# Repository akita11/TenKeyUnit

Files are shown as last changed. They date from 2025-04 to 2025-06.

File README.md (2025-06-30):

# TenKey UNIT

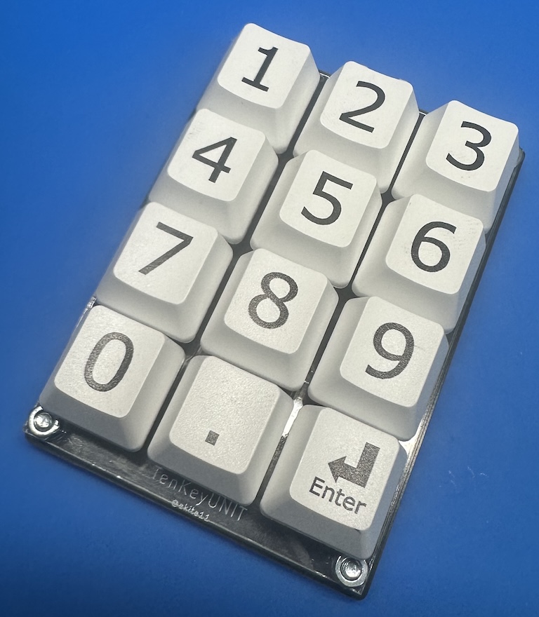
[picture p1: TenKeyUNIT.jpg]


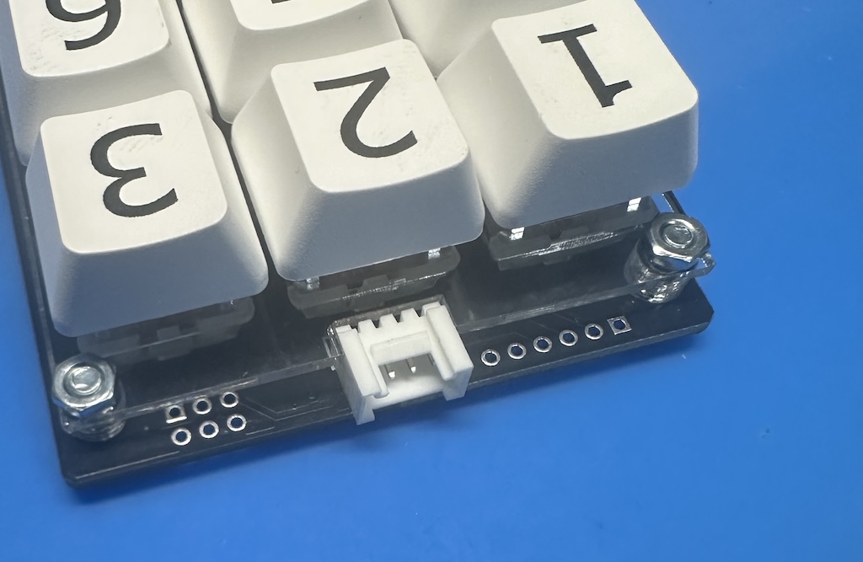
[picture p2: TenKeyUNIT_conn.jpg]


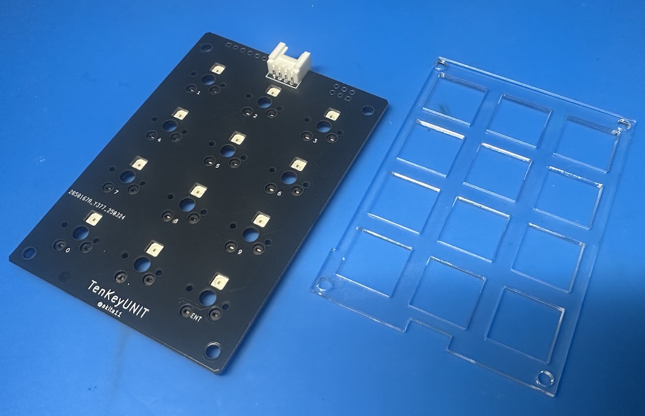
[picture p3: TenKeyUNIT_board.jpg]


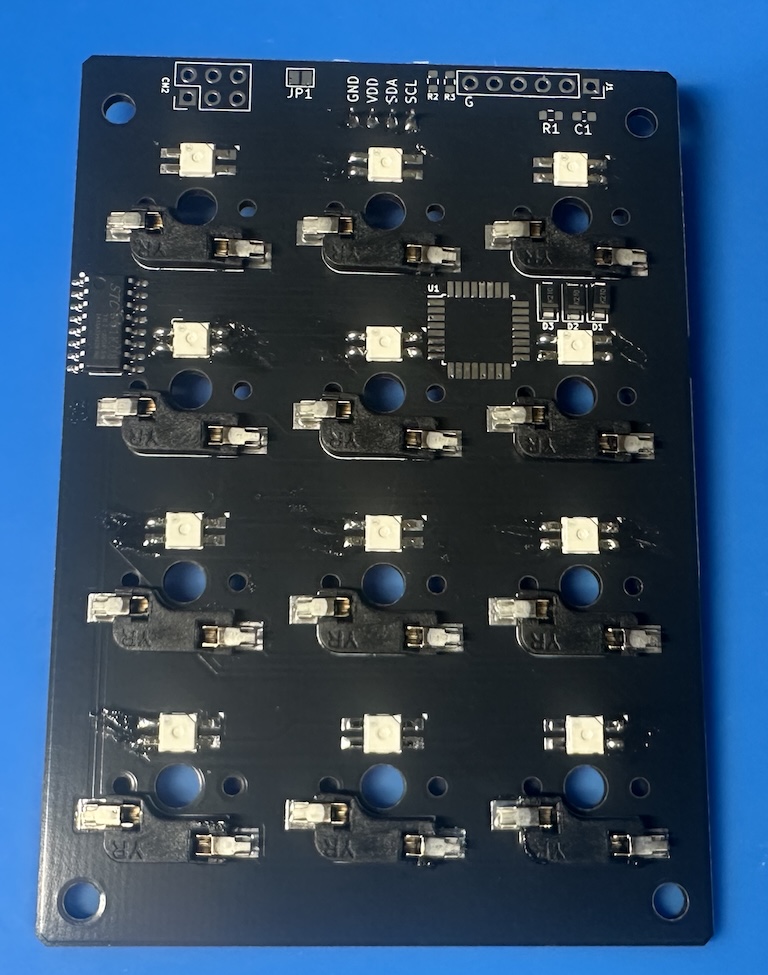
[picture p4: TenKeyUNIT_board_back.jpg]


GroveコネクタでM5Stack等の接続できる、数字の入力に便利なテンキーです。M5Stackの[CardKB Mini](https://www.switch-science.com/products/8445)と制御方法は互換ですので、CardKB Mini用のライブラリやUIFlowブロックを使用することができます。

## 使い方

M5Stack等のマイコンとGroveコネクタとをGroveケーブルで接続します。起動時にLEDが光ります（LEDつき版のみ）。キーを押すとそのキーのLEDがフラッシュします（LEDつき版のみ）。押したキーの情報(ASCIIコード)はGrove経由(I2C通信)で取得できます。

## 技術的詳細

### Grove経由の制御方法

通信方式はI2Cで、スレーブデバイス（I2Cアドレス=0x5f(7bit表記)）として動作します。マスタ側からI2C Readを行うと、直近で押したキーのASCIIコードを返します。

### 制御マイコン

制御マイコンはSTCmicro社のSTC8G08K-SOP16です。STCmicro社の書き込みツールをつかってファームウエアの書き換えを行うことができます。なおファームウエアのコンパイル方法や書き込み方法は、[STC8G_ProMini](https://www.switch-science.com/products/8216)のサポートページ等の情報を参照してください。

## 組立時の注意事項

プレート板（キースイッチ固定用）は表と裏があります。キースイッチがはまる穴が、基板上のキースイッチの位置にくる向きにしてください。またスペーサは2個重ねて（高さ3mmになります）ネジで固定します。

## Author

Junichi Akita (@akita11) / akita@ifdl.jp

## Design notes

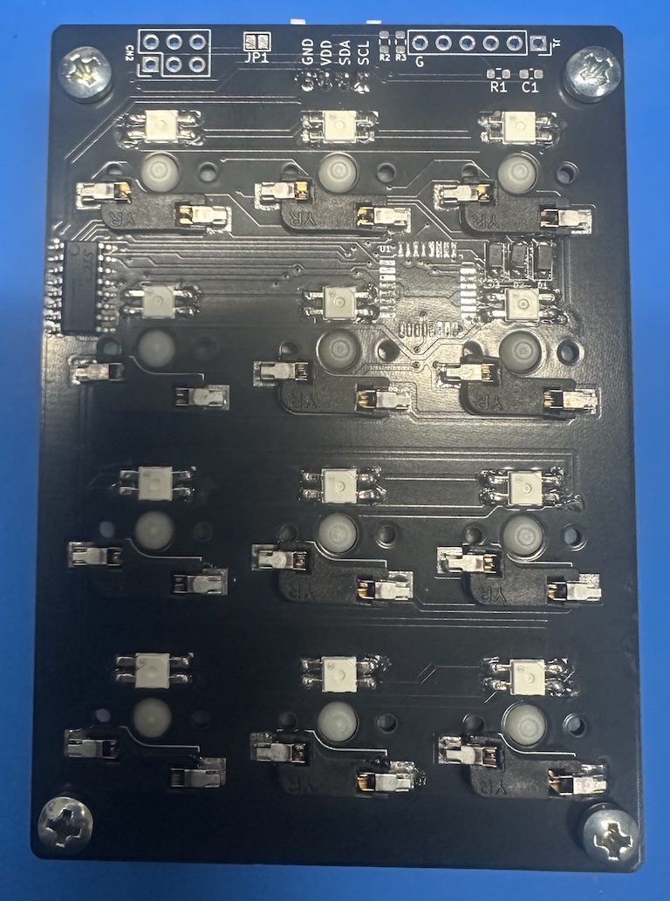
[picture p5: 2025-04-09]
TenKeyUNIT_back.jpg

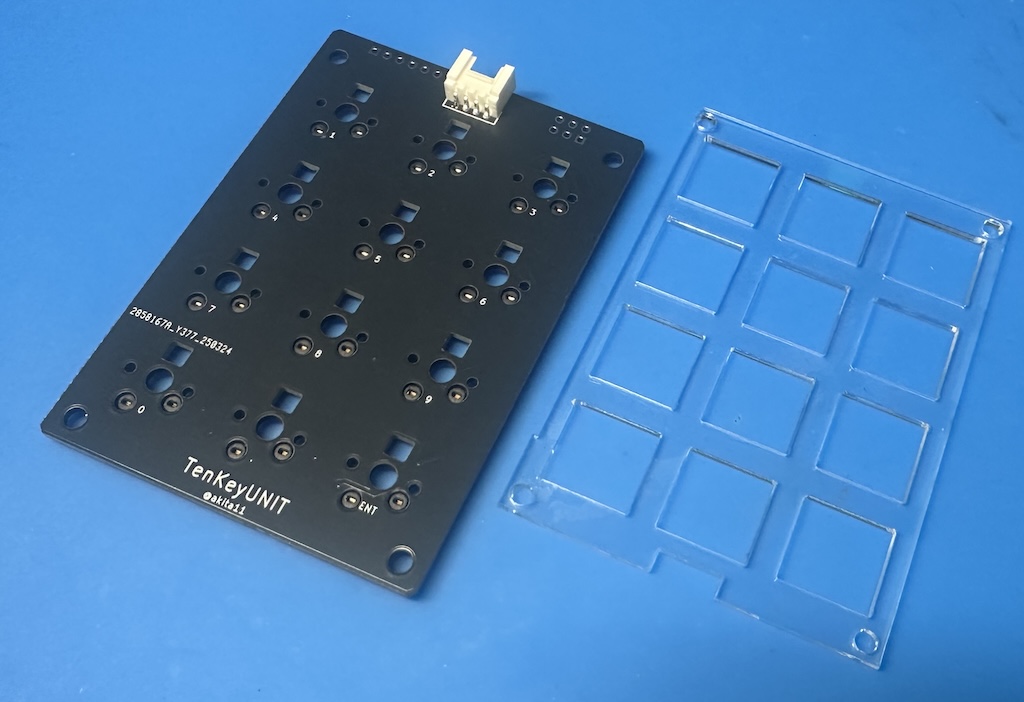
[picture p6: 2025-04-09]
TenKeyUNIT_board_noLED.jpg

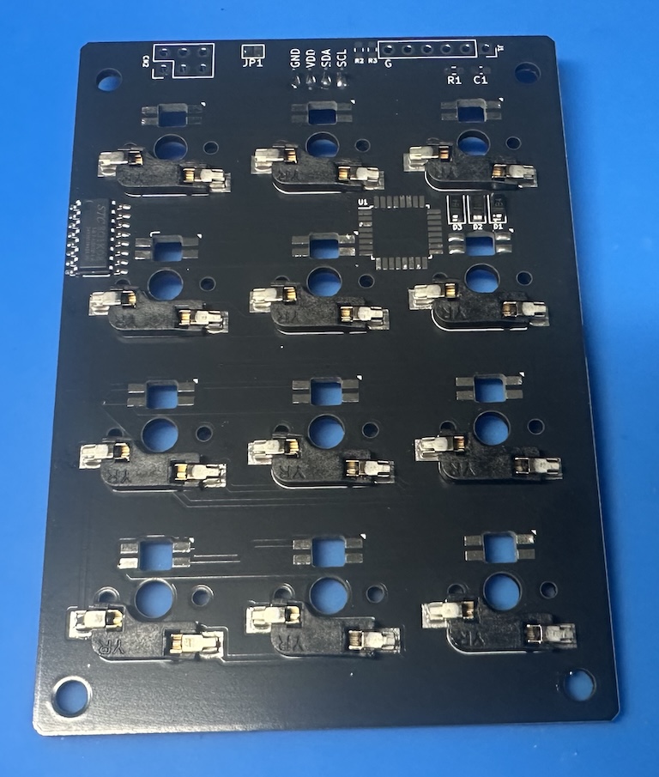
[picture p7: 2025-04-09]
TenKeyUNIT_board_noLED_back.jpg

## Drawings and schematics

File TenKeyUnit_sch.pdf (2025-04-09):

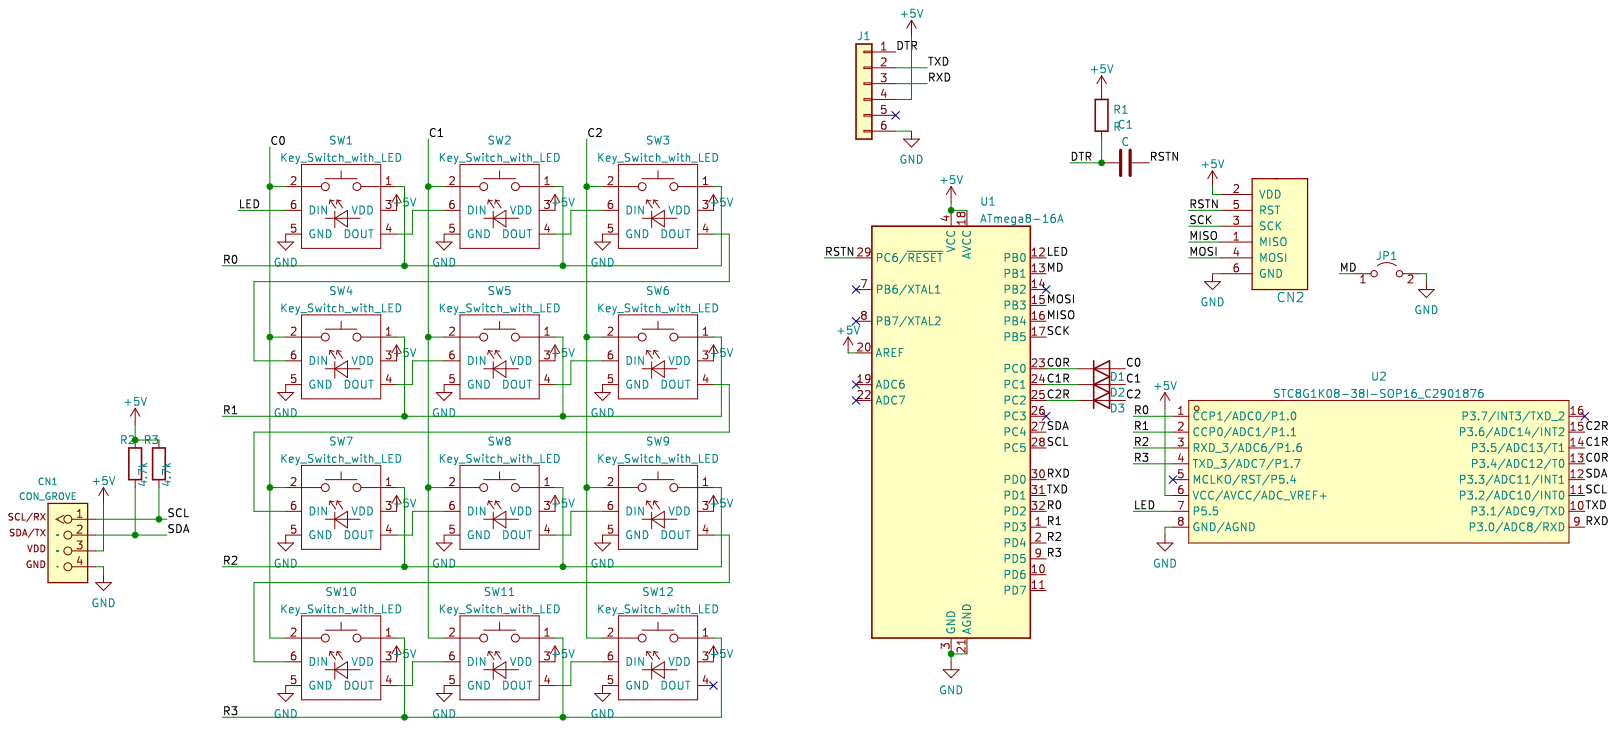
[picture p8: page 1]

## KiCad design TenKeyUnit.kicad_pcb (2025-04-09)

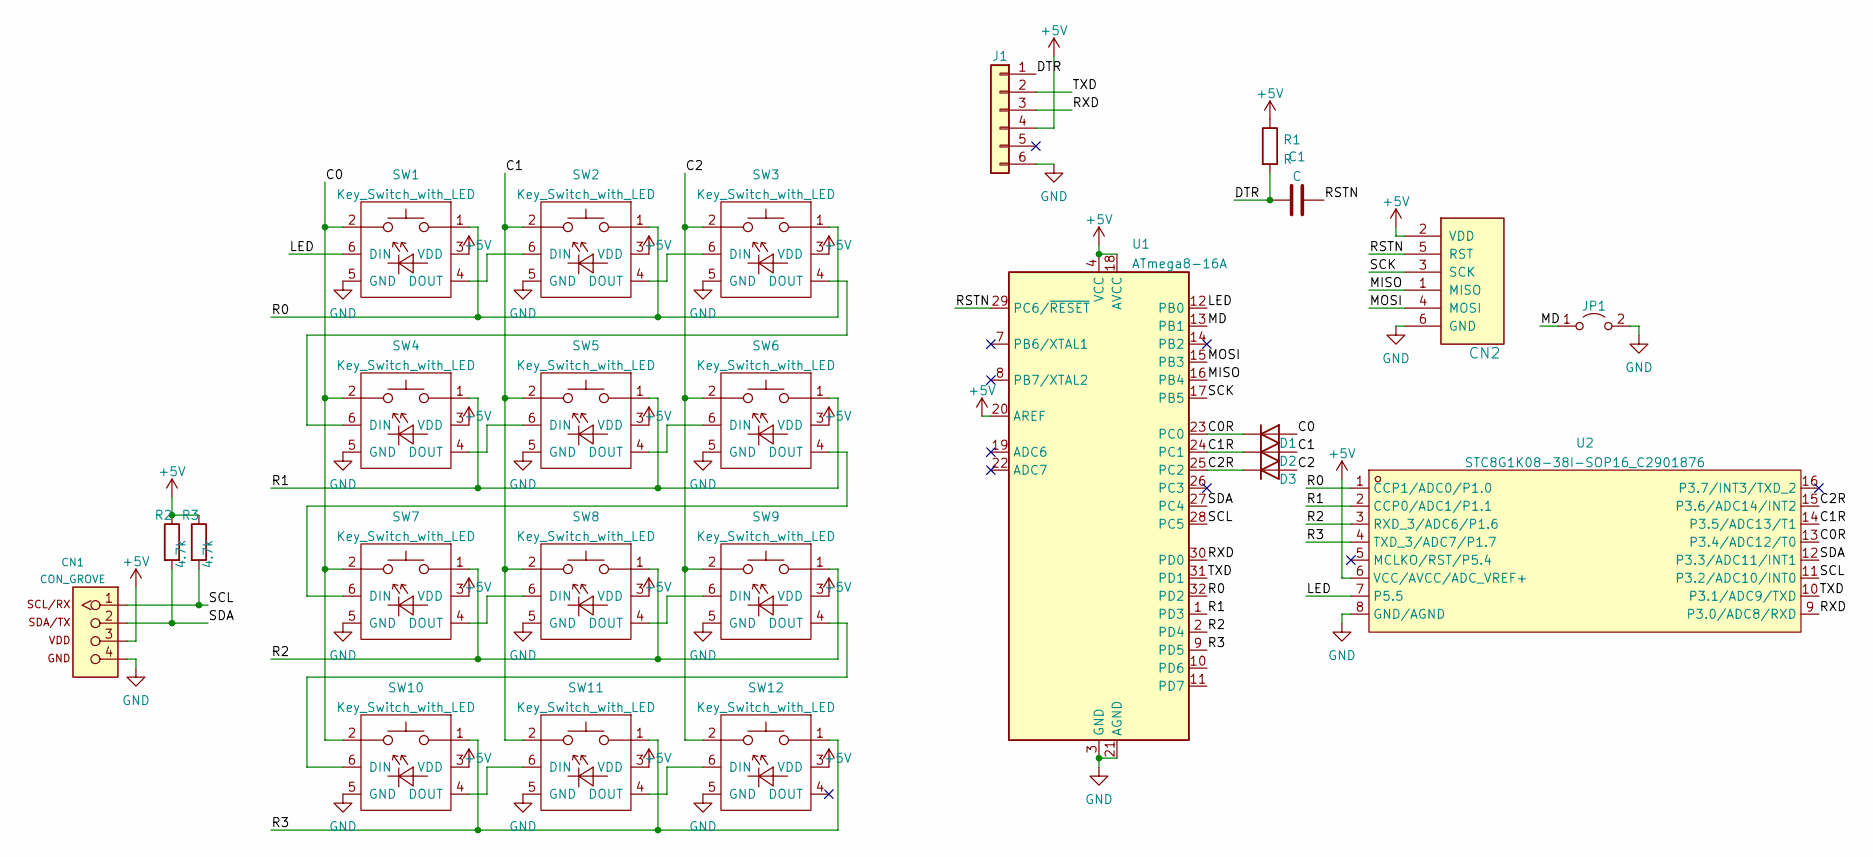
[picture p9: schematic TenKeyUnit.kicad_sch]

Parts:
C1: C; C_0603_1608Metric
CN1: CON_GROVE; CON_GROVE_H_roundPad
CN2: CON_AVRISP; PinHeader_2x03_P2.54mm_Vertical
D1, D2, D3: D; D_SOD-123F
J1: Conn_01x06; PinSocket_1x06_P2.54mm_Vertical
JP1: Jumper_2_Open; SolderJumper-2_P1.3mm_Open_Pad1.0x1.5mm
R1: R; R_0603_1608Metric
R2, R3: 4.7k; R_0603_1608Metric
SW1, SW2, SW3, SW4, SW5, SW6, SW7, SW8, SW9, SW10, SW11, SW12: Key_Switch_with_LED; MX_Socket_LED
U1: ATmega8-16A; TQFP-32_7x7mm_P0.8mm
U2: STC8G1K08-38I-SOP16_C2901876; SOP-16_L9.9-W3.9-P1.27-LS6.0-BL; LCSC Part C2901876

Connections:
+5V: CN1.3, CN2.2 (VDD), J1.4, R1.1, R2.1, R3.1, SW1.3 (VDD), SW2.3 (VDD), SW3.3 (VDD), SW4.3 (VDD), SW5.3 (VDD), SW6.3 (VDD), SW7.3 (VDD), SW8.3 (VDD), SW9.3 (VDD), SW10.3 (VDD), SW11.3 (VDD), SW12.3 (VDD), U1.4 (VCC), U1.6 (VCC), U1.18 (AVCC), U1.20 (AREF), U2.6 (VCC/AVCC/ADC_VREF+)
/C0: D1.2 (A), SW1.2, SW4.2, SW7.2, SW10.2
/C0R: D1.1 (K), U1.23 (PC0), U2.13 (P3.4/ADC12/T0)
/C1: D2.2 (A), SW2.2, SW5.2, SW8.2, SW11.2
/C1R: D2.1 (K), U1.24 (PC1), U2.14 (P3.5/ADC13/T1)
/C2: D3.2 (A), SW3.2, SW6.2, SW9.2, SW12.2
/C2R: D3.1 (K), U1.25 (PC2), U2.15 (P3.6/ADC14/INT2)
/DTR: C1.1, J1.1, R1.2
/LED: SW1.6 (DIN), U1.12 (PB0), U2.7 (P5.5)
/MD: JP1.1 (A), U1.13 (PB1)
/MISO: CN2.1 (MISO), U1.16 (PB4)
/MOSI: CN2.4 (MOSI), U1.15 (PB3)
/R0: SW1.1, SW2.1, SW3.1, U1.32 (PD2), U2.1 (CCP1/ADC0/P1.0)
/R1: SW4.1, SW5.1, SW6.1, U1.1 (PD3), U2.2 (CCP0/ADC1/P1.1)
/R2: SW7.1, SW8.1, SW9.1, U1.2 (PD4), U2.3 (RXD_3/ADC6/P1.6)
/R3: SW10.1, SW11.1, SW12.1, U1.9 (PD5), U2.4 (TXD_3/ADC7/P1.7)
/RSTN: C1.2, CN2.5 (RST), U1.29 (PC6/~RESET)
/RXD: J1.3, U1.30 (PD0), U2.9 (P3.0/ADC8/RXD)
/SCK: CN2.3 (SCK), U1.17 (PB5)
/SCL: CN1.1, R3.2, U1.28 (PC5), U2.11 (P3.2/ADC10/INT0)
/SDA: CN1.2, R2.2, U1.27 (PC4), U2.12 (P3.3/ADC11/INT1)
/TXD: J1.2, U1.31 (PD1), U2.10 (P3.1/ADC9/TXD)
GND: CN1.4, CN2.6 (GND), J1.6, JP1.2 (B), SW1.5 (GND), SW2.5 (GND), SW3.5 (GND), SW4.5 (GND), SW5.5 (GND), SW6.5 (GND), SW7.5 (GND), SW8.5 (GND), SW9.5 (GND), SW10.5 (GND), SW11.5 (GND), SW12.5 (GND), U1.3 (GND), U1.5 (GND), U1.21 (AGND), U2.8 (GND/AGND)
unnamed: SW1.4 (DOUT), SW2.6 (DIN)
unnamed: SW2.4 (DOUT), SW3.6 (DIN)
unnamed: SW3.4 (DOUT), SW4.6 (DIN)
unnamed: SW4.4 (DOUT), SW5.6 (DIN)
unnamed: SW5.4 (DOUT), SW6.6 (DIN)
unnamed: SW6.4 (DOUT), SW7.6 (DIN)
unnamed: SW7.4 (DOUT), SW8.6 (DIN)
unnamed: SW8.4 (DOUT), SW9.6 (DIN)
unnamed: SW10.4 (DOUT), SW11.6 (DIN)
unnamed: SW9.4 (DOUT), SW10.6 (DIN)
unnamed: SW11.4 (DOUT), SW12.6 (DIN)

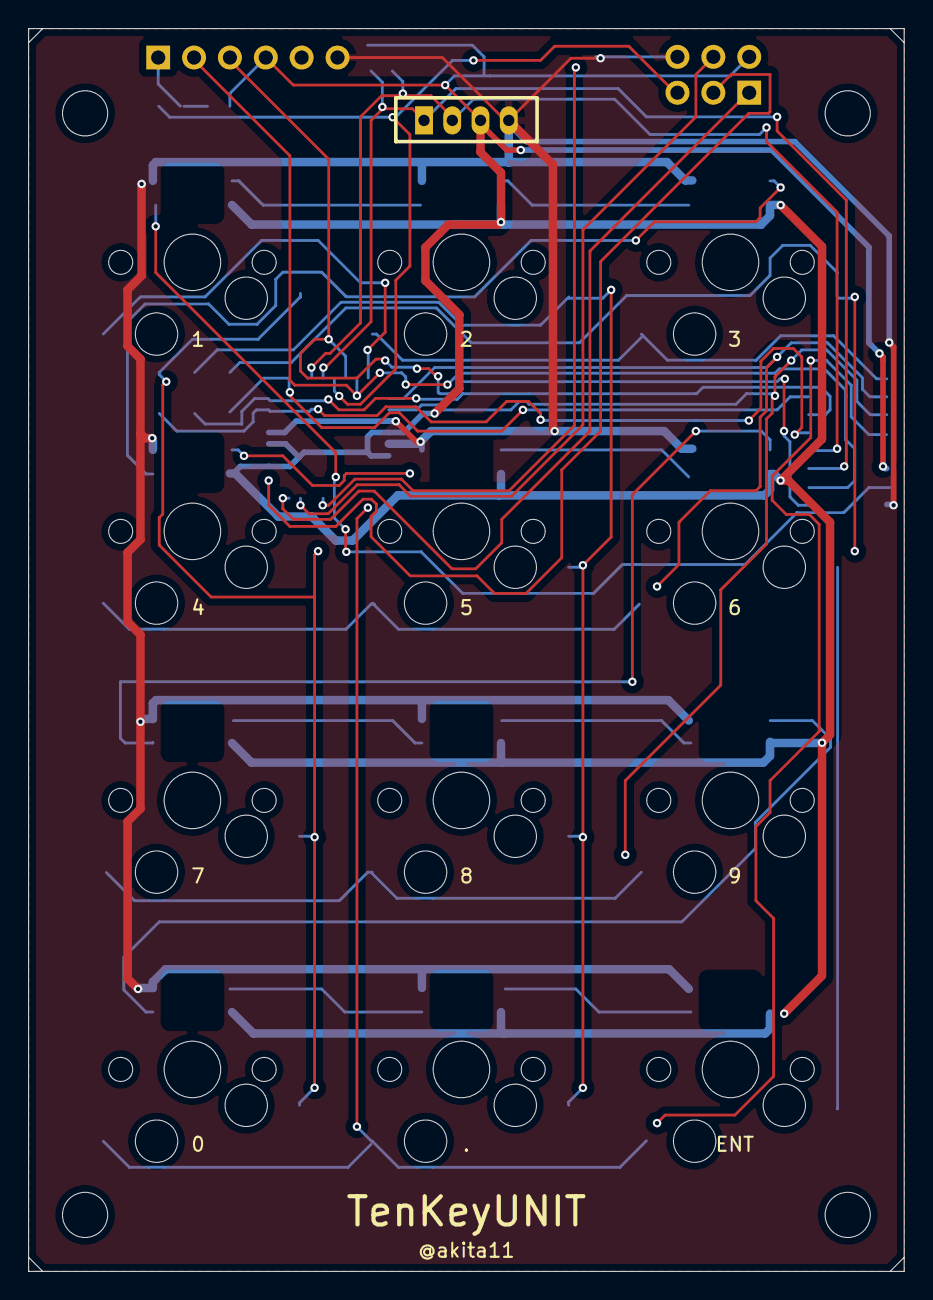
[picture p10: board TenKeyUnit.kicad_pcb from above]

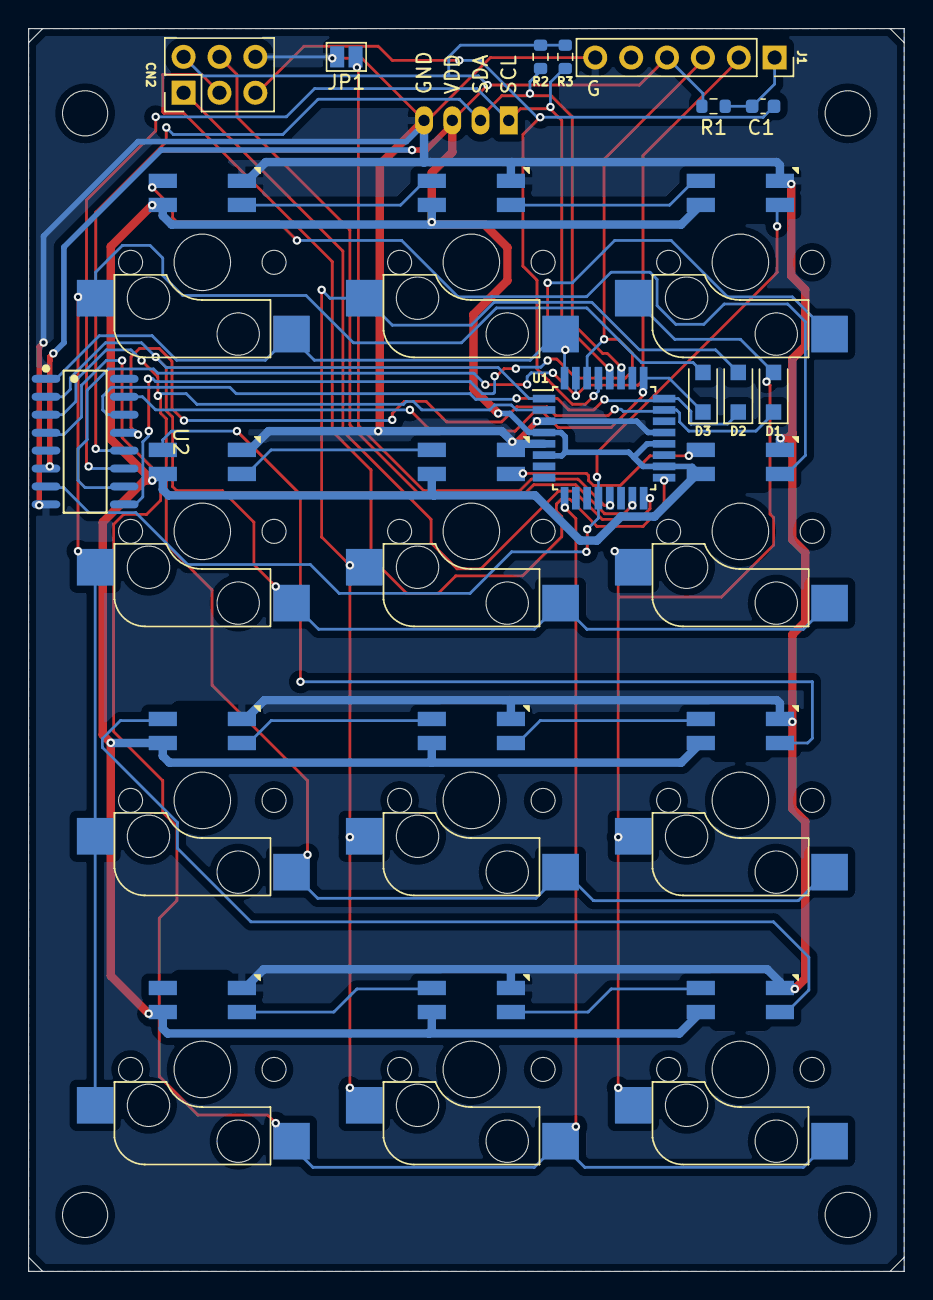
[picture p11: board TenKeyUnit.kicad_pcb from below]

Board: 2 copper layers, 62.0 x 88.0 mm, 25 parts (24 on the bottom side), 34 nets.

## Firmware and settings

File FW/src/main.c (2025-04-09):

#include <stdint.h>
#include "fw_reg_stc8g.h"
#include <stdlib.h>

// STC8G1K08A-36I-SOP16
// Grove: SCL(P3.2)-SDA(P3.3)-VDD-GND

//     P34(o) P35(o) P36(o)
// P10  1      2      3         LED#0 #1  #2
// P11  4      5      6            #3 #4  #5
// P16  7      8      9            #6 #7  #8
// P17  .      0     ENT           #9 #10 #11

#define pinR0    P10
#define pinR1    P11
#define pinR2    P16
#define pinR3    P17
#define pinC0    P34
#define pinC1    P35
#define pinC2    P36
#define pinRXD   P30 // P3.0 / Grove-p2
#define pinTXD   P31 // P3.1 / Grove-p1
#define pinSCL   P32 // P3.2
#define pinSDA   P33 // P3.3
#define pinMD    P37 // P3.7, not coneccted in v1

#define FOSC 11059200UL

#define I2C_SLAVE_ADDR 0x5f // 7bit expression

#include "WS2812_P5_5.c"
void neopixel_show_long_P5_5(uint32_t dataAndLen); 
#define neopixel_show_P5_5(ADDR,LEN) neopixel_show_long_P5_5((((uint16_t)(ADDR)) & 0xFFFF) | (((uint32_t)(LEN) & 0xFFFF) << 16)); 

#define setPixel(INDEX, R, G, B)		   \
  {                                                \
    __xdata uint8_t *ptr = (ledData) + ((INDEX)*3);   \
    ptr[0] = (G);                                  \
    ptr[1] = (R);                                  \
    ptr[2] = (B);                                  \
  };

#define showPixels() neopixel_show_P5_5(ledData, NUM_BYTES)


#define NUM_LEDS 12
#define NUM_BYTES (NUM_LEDS * 3)

__xdata uint8_t ledData[NUM_BYTES]; // 3byte/LED

__xdata uint8_t led_r;
__xdata uint8_t led_g;
__xdata uint8_t led_b;

unsigned char sinTable[46] = {0, 0, 1, 1, 1, 1, 2, 2, 2, 2, 3, 3, 3, 4, 4, 4, 4, 4, 5, 5, 5, 5, 6, 6, 6, 6, 6, 6, 7, 7, 7, 7, 7, 7, 7, 8, 8, 8, 8, 8, 8, 8, 8, 8, 8, 8};

void setColorHSV(unsigned int hue, unsigned char sat, unsigned char val) {
  hue = (hue * 1530L + 32768) / 65536;
  if (hue < 510) { // Red to Green-1
    led_b = 0;
    if (hue < 255) { //   Red to Yellow-1
      led_r = 255;
      led_g = hue;       //     g = 0 to 254
    } else {         //   Yellow to Green-1
      led_r = 510 - hue; //     r = 255 to 1
      led_g = 255;
    }
  } else if (hue < 1020) { // Green to Blue-1
    led_r = 0;
    if (hue < 765) { //   Green to Cyan-1
      led_g = 255;
      led_b = hue - 510;  //     b = 0 to 254
    } else {          //   Cyan to Blue-1
      led_g = 1020 - hue; //     g = 255 to 1
      led_b = 255;
    }
  } else if (hue < 1530) { // Blue to Red-1
    led_g = 0;
    if (hue < 1275) { //   Blue to Magenta-1
      led_r = hue - 1020; //     r = 0 to 254
      led_b = 255;
    } else { //   Magenta to Red-1
      led_r = 255;
      led_b = 1530 - hue; //     b = 255 to 1
    }
  } else { // Last 0.5 Red (quicker than % operator)
    led_r = 255;
    led_g = led_b = 0;
  }

  // Apply saturation and value to R,G,B, pack into 32-bit result:
  unsigned long v1 = 1 + val;  // 1 to 256; allows >>8 instead of /255
  unsigned int s1 = 1 + sat;  // 1 to 256; same reason
  unsigned char s2 = 255 - sat; // 255 to 0

  led_r = (((((led_r * s1) >> 8) + s2) * v1) >> 8);
  led_g = (((((led_g * s1) >> 8) + s2) * v1) >> 8);
  led_b = (((((led_b * s1) >> 8) + s2) * v1) >> 8);
}

// hue = 0-179(360/2)
void setRGB(unsigned int hue, unsigned char sat, unsigned char val) {
  for (unsigned char i = 0; i < NUM_LEDS; i++) {
    setColorHSV(hue, sat, val);
    setPixel(i, led_r, led_g, led_b); //Choose the color order depending on the LED you use
    hue += 655;
  }
  showPixels();
}

long map(long x, long in_min, long in_max, long out_min, long out_max) {
  return (x - in_min) * (out_max - out_min) / (in_max - in_min) + out_min;
}

void delay100ms(unsigned char n) //@11.0592MHz, from STC-ISP
{
  unsigned char i, j, k;
  do{
    __asm__("nop");
    i = 6; j = 157; k = 59;
    do { do{ while (--k); } while (--j);} while (--i);
  } while (--n);
}

void delay10ms(unsigned char n)	//@11.0592MHz, from STC-ISP
{
  unsigned char i, j;
  do{
    __asm__("nop"); __asm__("nop");
    i = 144; j = 157; do{ while (--j); } while (--i);
  } while (--n);
}

void delay1ms(unsigned char n) //@11.0592MHz, from STC-ISP
{
  unsigned char i, j;
  do{
    i = 15; j = 90;
    do {while (--j);} while (--i);
  } while (--n);
}

uint8_t key = 0;
uint8_t md = 0;
uint8_t st = 0;

char keyMap[] = {'1', '2', '3', '4', '5', '6', '7', '8', '9', '0', '.', 0x0d};

uint8_t scanColumn = 0;

unsigned char d = 0;

void sendByte(unsigned char c)
{
  //  while(SCON & 0x02); // wait fot TX complete
  SBUF = c;
}

void main(void)
{
  // M1=0/M0=0 : QB/quasi bidirectional
  // M1=0/M0=1 : PP/push-pull output
  // M1=1/M0=0 : IN/input
  // M1=1/M0=1 : OD/open-drain
  P3M1 = 0x00; P3M0 = 0x70; // set P3.0-3=QB, P3.4-6=PP
  P1M1 = 0x00; P1M0 = 0x00; // set P1.0-P1.7=QB
  P5M1 = 0x00; P5M0 = 0x00; // set P5.4=QB
  P_SW2 = 0xb0; // I2C=P3.2(SCL)/P3.3(SDA), XFR access enabled
  P3PU |= 0x0c; // enable pull-up of P3.2/P3.3 (does it works?)
  
  // 9600bpsU(UART1)@11.0592MHz, from STC-ISP
  PCON &= 0x7F;	// Baudrate no doubled
  SCON = 0x50;  // 8 bits and variable baudrate (Mode1), RX enabled
  AUXR |= 0x40; // imer clock is 1T mode
  AUXR &= 0xFE;	// UART 1 use Timer1 as baudrate generator
  TMOD &= 0x0F;	// Set timer work mode
  TMOD |= 0x20;	// Set timer work mode
  TL1 = 0xDC;	// Initial timer value
  TH1 = 0xDC;	// Set reload value
  ET1 = 0;	// Disable Timer1 interrupt
  TR1 = 1;	// Timer1 start run

  I2CCFG = 0x81; // enable I2C, slave mode, speed clock=1
  I2CSLADR = I2C_SLAVE_ADDR << 1;

  I2CSLST = 0x00;
  I2CSLCR = 0x00;
  I2CTXD = 0x00;

  // mode check, for v1.1
  P1 |= 0x80; __asm__("nop"); __asm__("nop");
  if ((P1 & 0x80) == 0) md = 1; else md = 0;

  //     P34(o) P35(o) P36(o)
  // P10  1      2      3         LED#0 #1  #2
  // P11  4      5      6            #3 #4  #5
  // P16  7      8      9            #6 #7  #8
  // P17  .      0     ENT           #9 #10 #11

  #define LED_BRIGHTNESS 50

  unsigned int brightness = LED_BRIGHTNESS;

  for (unsigned char i = 0; i < NUM_LEDS; i++) setPixel(i, 0, 0, 0);
  showPixels();

  // Fade In
  for (brightness = 0; brightness < LED_BRIGHTNESS; brightness++){
    for (unsigned char i = 0; i < NUM_LEDS; i++)
      setPixel(i, brightness, brightness, brightness);
    showPixels();
    delay1ms(1);
  }
  /*
  for (unsigned char i = 0; i < NUM_LEDS; i++)
  {
    setPixel(i, LED_BRIGHTNESS, LED_BRIGHTNESS, LED_BRIGHTNESS);
    showPixels();
    //    delay10ms(3);
    delay10ms(1);
  }
    */
  // Rotate
  //  for (unsigned int baseHue = 0xFF00; baseHue > 0; baseHue -= 0x100)
  for (unsigned int baseHue = 0; baseHue < 0xfdff; baseHue += 0x100)
  {
    for (unsigned int i = 0; i < NUM_LEDS; i++)
    {
      //      setLED(i, ledIndex[index], map(index, 0, ROWS * COLS, 0, 65535) + (uint16_t)baseHue, LED_BRIGHTNESS);
      setColorHSV(map(i, 0, NUM_LEDS, 0, 65535) + (unsigned int)baseHue, 250, LED_BRIGHTNESS);
      setPixel(i, led_r, led_g, led_b);
    }
    showPixels();
    delay1ms(1);
    //delay1ms(8);
  }
  
  // Fade Out
  //  for (unsigned int baseHue = 0xFF00; baseHue > 0; baseHue -= 0x100)
  for (unsigned int baseHue = 0; baseHue < 0xfeff; baseHue += 0x100)
  {
    brightness--;
    for (unsigned char i = 0; i < NUM_LEDS; i++)
    {
      setColorHSV(map(i, 0, NUM_LEDS, 0, 65535) + (unsigned int)baseHue, 250, brightness);
      setPixel(i, led_r, led_g, led_b);
    }
    showPixels();
    if (brightness == 0) break;
    delay1ms(1);
    //delay1ms(8);
  }

  for (unsigned char i = 0; i < NUM_LEDS; i++) setPixel(i, 0, 0, 0);
  showPixels();

  while(1){
    key = 0;
    for (scanColumn = 0; scanColumn < 3; scanColumn++){
      P3 |= 0x70;
      switch(scanColumn){
      case 0 : P3 &= ~0x10; break; // P3.4=0
      case 1 : P3 &= ~0x20; break; // P3.5=0
      case 2 : P3 &= ~0x40; break; // P3.6=0
      }
      delay1ms(1);
      P1 |= 0xc3; __asm__("nop"); __asm__("nop");
      if ((P1 & 0x01) == 0) key =  1 + scanColumn;
      if ((P1 & 0x02) == 0) key =  4 + scanColumn;
      if ((P1 & 0x40) == 0) key =  7 + scanColumn;
      if ((P1 & 0x80) == 0) key = 10 + scanColumn;
    }

    if (md == 1){ // swap 1-2-3 / 7-8-9, for v1.1
      if (key >= 1 && key <= 3) key = key - 6;
      else if (key >= 7 && key <= 9) key = key - 6;
    }
    
    if (st == 0 && key != 0){
      st = 1;
      unsigned char r, g, b;
      // r = rand() & 0x1f; g = rand() & 0x1f; b = rand() & 0x1f; // random color
      //      r = 20; g = 20; b = 20; // white
      //      r = 100; g = 100; b = 100; // white
      r = 200; g = 200; b = 200; // white
      setPixel(key - 1, r, g, b); showPixels();
      delay100ms(1);
      setPixel(key - 1, 0, 0, 0); showPixels();
    }
    else{
      if (st == 2 && key == 0) st = 0;
    }


    if (I2CSLST & 0x10){ // I2C SENT event
      I2CSLST &= ~0x10;
      if (I2CSLST & 0x02){
	//Stop receiving data when receiving NAK
	if (st == 1){
	  I2CTXD = keyMap[key - 1]; st = 2;
	}
	else I2CTXD = 0x00;
      }
      else{
	//Continue reading data when receiving ACK
	if (st == 1){
	  I2CTXD = keyMap[key - 1]; st = 2;
	}
	else I2CTXD = 0x00;
      }
    }
  }
}

/*
void I2C_ISR(void) __interrupt (24)
{
  //  _push_(P_SW2);
  //  P_SW2 |= 0x80;
  if (I2CSLST & 0x40){ // START received
    I2CTXD = d++;
    I2CSLST &= ~0x40;
  }
  //  _pop_(P_SW2);
}
*/
